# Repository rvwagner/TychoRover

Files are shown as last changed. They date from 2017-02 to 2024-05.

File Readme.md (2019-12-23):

# Tycho Rover Code

This project contains the code needed to drive the Tycho prototype lunar rover.  Currently, it is set up to drive a 1/10th-scale model using an XBox 360 controller.

There is also an [OpenSCAD][] file that can be used to 3D print a copy of the scale model.  There are detailed assembly instructions and a parts manifest at the top of that file.  Be warned that the central frame part is larger than most 3D printers- it should be possible to change the scale factor (variable `X`) to a smaller number (e.g. `25.4/11` or `25.4/12` for 1/11 or 1/12th scale, respectively) to make it fit on your printer's bed, although I have not tested that everything fits together at other scales.  You may also need to adjust the `margin` and `innermargin` variables for your printer.

## Dependencies

Requires that [ROS][] be installed (tested on ROS Kinetic Kame on Ubuntu 16.04), and requires the following ROS packages: 
- [Joy][]: `sudo apt-get install ros-kinetic-joy`
- [ROSSerial][]: `sudo apt-get install ros-kinetic-rosserial`
- [ROSSerial_Arduino][]: `sudo apt-get install ros-kinetic-rosserial-arduino`
- [ROSBridge][]: `sudo apt-get install ros-kinetic-rosbridge_suite`

Requires that the [Arduino][] IDE be installed: `sudo apt-get install arduino`

### For the CAN stuff [in progress]

- [CANard][]

    `git clone https://github.com/normaldotcom/CANard.git`
    
    `cd CANard`
    
    `[sudo] python setup.py install`

- (if using SocketCAN) [can-utils][]: `sudo apt install can-utils`
- (if using SocketCAN) slcan kernel module, if not already built [instructions](https://wiki.linklayer.com/index.php/CANtact_on_Raspberry_Pi).

The CANard module requires Python 3 (todo: figure out why), while the default ROS Python support in Kinetic is Python 2.  You may need to specially install Python 3 moduels for ROS:

    `sudo apt-get install python3-catkin-pkg-modules`

    `sudo apt-get install python3-rospkg-modules`

### Firefox

The GUI requires Firefox.  Unfortunately, Firefox 53 and later are broken on Raspberry Pi MATE Ubuntu.  To install, first uninstall Firefox, then download and install version 52:

    sudo apt-get purge firefox
    wget 'http://ports.ubuntu.com/pool/main/f/firefox/firefox_52.0.2+build1-0ubuntu0.12.04.1_armhf.deb'
    sudo dpkg -i firefox_52.0.2+build1-0ubuntu0.12.04.1_armhf.deb
    sudo apt-mark hold firefox

## Running the code

There is a launch file that starts up all the required ROS nodes:

    roslaunch tycho tycho.launch

Once the roslaunch file has finished, go to the `web/index.html` file in Firefox to view the GUI interface.

## Controls

On an XBox 360 controller, the controls are as follows:
- Left stick: Drive and steer
- A button: Enable driving in reverse (otherwise pulling stik back brakes)
- B button: Change steering mode to strafing
- X button: Emergency stop (disabled by allowing stick to return to neutral)

## Useful command-line snippets

Rebuilding ROS Arduino libraries:

    source ~/catkin_ws/devel/setup.bash      # Must re-source the workspace, even if you already have?
    rm -rf ~/sketchbook/libraries/ros_lib/   # Need to delete the libraries before rebuilding them
    rosrun rosserial_arduino make_libraries.py ~/sketchbook/libraries/

[ROS]: http://wiki.ros.org/ROS/Installation
[Joy]: http://wiki.ros.org/joy
[ROSSerial]: http://wiki.ros.org/rosserial
[ROSSerial_Arduino]: http://wiki.ros.org/rosserial_arduino
[ROSBridge]: http://wiki.ros.org/rosbridge_suite
[Arduino]: http://arduino.cc
[OpenSCAD]: http://www.openscad.org
[can-utils]: https://github.com/linux-can/can-utils
[CANard]: https://github.com/normaldotcom/CANard

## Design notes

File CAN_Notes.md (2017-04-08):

# CAN/CANable/Ubuntu Notes

CANable info page:
canable.io

Need to install can-utils:

    sudo apt install can-utils

On Raspberry Pi, also need to install slcan kernel module separately:
https://wiki.linklayer.com/index.php/CANtact_on_Raspberry_Pi

To get CANard installed,

    git clone https://github.com/normaldotcom/CANard.git
    cd CANard
    [sudo] python setup.py install
    [cd ..; rm -rf CANard/]

- - - 

To test:

    sudo modprobe can
    sudo modprobe slcan
    sudo slcand -o -c -s5 /dev/ttyACM0 can0
    sudo ifconfig can0 up

To automatically load the kernel modules on boot, add the lines "can" and "slcan" to `/etc/modules`.

Do not use slcand if you are using CANard's cantact module.

Test commands:

    candump can0 & # Or run without backgrounding in a separate window
    cansend can0 201#000A.002D

Be warned that apparently if there isn't something on the other end recieving messages, the transmit buffer fills up after ~10 messages.

# CAN and RoboTeq Controllers

CAN commands are always executed
MicroBASIC is identical priority to Serial, and are also subject to the watchdog timer.
In non-Serial modes, the controller will still respond to info queries over serial wihtout affecting control. DItto queries over CAN.

Serial section starts page 141
- They advise against using USB connection in the field- RS232 is more resilient to eletrical disruptions.
- Commands are not case-sensitive
- Underscore is an alias of carriage return
- Default watchdog is 1sec

CAN sections are 149 and ... and 169 (CANopen)
- Supports RawCAN, MiniCAN, CANopen (I know that's a ROS node for this), and RoboCAN
- - MiniCAN is a subset of OpenCAN
- - RoboCAN is proprietary, but designed for networking RoboTeq controllers
- Some controllers disable CAN while USB is connected- check datasheet
- A CAN packet/frame is 11-bit header and 0-8 byte LSB payload
- CAN packets can/should/must be interpreted by MicroBASIC scripts :-D
- In MiniCAN mode, incoming packets are automatically written to VAR9-VAR16

- RoboCAN is interesting, but not useful for us without building a custom RoboCAN-interpreting node.  Since a MiniCAN node would also need to be custom (but might be possible to build with just config files using ros_canopen), there will be no particular effort savings.

- Need to refer to general CAN documentation for bit-rate given our cable length.  Can probably hit the 1Mbps level, though default is 125kbps.

- CANopen may be a better way to go, assuming there's a general way to send data- they have a CANopen-compliant dictionary on page 173, which should allow building the ros_canopen config files.
- - As in MiniCAN, Controller will automatically transmit up to four types of packet containing settable values (VAR1-8) at an adjustable frequency (TPDO1-4).  Slight difference from MiniCAN in that only 8 vars are transmitted, as opposed to 4 4-byte, 4 2-byte and 32 bools. (Verify this in practice.)
- - As in MiniCAN, the RPDO1-4 packets write to VAR9-16. (Same difference as above.)
- - New part from CANopen is the ability to request and command specific values, bypassing the MicroBASIC script (such as e-stop)
- https://www.amazon.com/dp/B00ZW8N930/
- https://github.com/b/libusbcan
- This seems to be the go-to CAN adaptor: ~$200: http://www.peak-system.com/PCAN-USB.199.0.html?&L=1
- Here's a $25 version (out of stock) that is likely to do everything we need: http://protofusion.org/wordpress/2015/05/the-canable-a-small-usb-to-can-adapter/

- - -

MicroBASIC
- Integer (32bit) and boolean variables only - limit 1024/4096 ints and 1024 bools
- (I'll send the motor commands in RPM and radians, in order to avoid any need to update the controller code if the system layout changes?  No, it needs to know the tire diameter and steering arm length to function, so I might need to make those writable...)
- All variables set to 0/false on script first load/controller reset
- One of their suggested script actions is the limit the amp range based on heatsink temperature.
- scripts are activated every 1ms, after motion control processing is done.  Motor control takes priority.  They estimate ~50 lines of execution per activation.  Serial print is limited to 32 char/activation.
- Can upload scripts saved in .hex format from PC Utility over serial (page 183)
- NEVER set a script to auto-run unless you've made sure it doesn't crash immediately- if it does, you may need to reflash the firmware.

- - -

NUC-side CAN node:
- probably use ros_canopen for the actual communication
- Have a custom node watching the CAN node's messages
- - Track heartbeats, if any node goes silent for too long, throw an error
- - - Some level of control system should throw an estop (or harsh speed limit) if a controller goes out
- - - Probably the same level that keeps track of what the motor parameters are- call it "self-analysis"
- - When a status message (TPDO) comes in, translate to the appropriate "sensor" topics based on source ID, message type
- - If I do a single "motor status" topic, then send either when heartbeat fails or when last TPDO of the set from a controller comes in
- May have a separate node for transmission (why not?)
- - When a motor_command_final comes in, translate into CAN messages, publish to whatever ros_canopen takes
- - When an e-stop command comes in, send e-stop broadcast, as well as targeted "stop" messages.

## Manual NUC-side notes ##

CANsend documentation:
https://github.com/linux-can/can-utils/blob/master/cansend.c

Packet format:
    [three-hex-id]#[0-8 char hex data, with optional '.' separators]
    [header 0x000]#[data 0x00...]

Outgoing from controller: (not sure what Node ID is, as there isn't an obvious way to set it...  Probably broadcast.)
TPDO1: 0x180 & Node ID
TPDO2: 0x280 & Node ID
TPDO3: 0x380 & Node ID
TPDO4: 0x480 & Node ID

Incoming to controller:
RPDO1: 0x200 & Node ID
RPDO2: 0x300 & Node ID
RPDO3: 0x400 & Node ID
RPDO4: 0x500 & Node ID

So, to send RPDO1 to Node 1 with data 10,45:
201#000A.002D

E-stop Node 1 (see page 175):
Not sure what the "01" in the data is about. Seems unused.
601#8.2C.200C.00.01000000     # E-stop all channels
601#8.2C.200D.00.01000000     # Release e-stop
601#8.2C.200E.00.01000000     # "Stop [channel 1] in all modes", arg is channel

0x200E: Stop in all modes (command name MS)
- "The MS command is similar to the EX emergency stop command except that it is applied to the speci ed motor channel"

setcommand(_MSTOP, channel)

- - -

# MicroBASIC Script #

' See Page 210 for command, page 227 for queries; page 305 for config values ; page 344 for CAN bus

' Input: speed, in tenths of an RPM
'        angle, in tenths of a degree
'        scale factor = steerArmLength/tireRadius * 100
'        Heartbeat: any non-0 value that must be sent more often than HEARTBEAT_RECIEVE_RATE

#define STEER_BRAKE_PIN xx
#define DRIVE_BRAKE_PIN xx
#define COMMANDED_SPEED VAR9
#define COMMANDED_ANGLE VAR10
#define SPEED_SCALE_FACTOR_INPUT VAR11
#define NUC_IS_ALIVE VAR12
#define DATA_SEND_RATE 200
#define HEARTBEAT_RECIEVE_RATE 1000

' Use defines for readability and to allow for easy reversal of whether high or low activates the brakes
' _D0 is set pin low, _D1 is set pin high
#define BRAKES_ON _D0
#define BRAKES_OFF _D1

#define REPORT_TIMER = 1
#define KEEPALIVE_TIMER = 2

' First, make certain the brakes are on.
' They will be on when the controller is off.
SetCommand(BRAKES_ON, DRIVE_BRAKE_PIN)
SetCommand(BRAKES_ON, STEER_BRAKE_PIN)

' Set up status reporting
SetConfig(_CEN, 1)                  ' Start CANopen (comes with a default 100ms heartbeat)
SetConfig(_CTPS, 1, DATA_SEND_RATE) ' Send VAR1,2 every DATA_SEND_RATE ms
SetConfig(_CTPS, 1, DATA_SEND_RATE) ' Send VAR3,4 every DATA_SEND_RATE ms
SetConfig(_CTPS, 1, DATA_SEND_RATE) ' Send VAR5,6 every DATA_SEND_RATE ms
SetConfig(_CTPS, 1, 0)              ' Do not send VAR7,8

' Other initialization stuff
Max_Speed = GetConfig(MXRPM, 1)

' Wait for the controlling computer to check in and set the scaling parameter
GoSub SafeUntilSignal
Speed_Scale_Factor = SPEED_SCALE_FACTOR_INPUT

SetTimerCount(REPORT_TIMER, DATA_SEND_RATE)
SetTimerCount(KEEPALIVE_TIMER, HEARTBEAT_RECIEVE_RATE)

loop:
    ' (adjustments based on temperature?)
    
    Current_Steering_Speed = GetConfig(_S, 2) 'Get actual steering speed in RPM
    Current_Drive_Speed = GetConfig(_S, 1) 'Get actual steering speed in RPM
    
    ' (Current_Steering_Speed * Speed_Scale_Factor / 100) is the angular
    '  speed needed to coordinate the tire with the steering
    Final_Drive_Speed = COMMANDED_SPEED + Current_Steering_Speed * Speed_Scale_Factor / 100
    
    ' Convert angle in tenth-degrees to -1000/+1000 range
    Final_Angle = COMMANDED_ANGLE * 10 / 9

    If Final_Angle = GetValue(_F, 2) Then
        SetCommand(BRAKES_ON, STEER_BRAKE_PIN)
    Else 
        SetCommand(BRAKES_OFF, STEER_BRAKE_PIN)
        SetValue(_G, 2, Final_Angle)
    End If
    
    If Final_Drive_Speed = 0 && Current_Drive_Speed = 0 Then '[or braking commanded?]
        SetCommand(BRAKES_ON, DRIVE_BRAKE_PIN)
    Else
        SetCommand(BRAKES_OFF, DRIVE_BRAKE_PIN)
    End If
    
    If Final_Drive_Speed <> Current_Drive_Speed Then
        ' apply motor speed to drive motor
        SetValue(_G, 1, Final_Drive_Speed*100/Max_Speed)
    End If
    
    ' Copy motor status if it is time
    If GetTimerState(REPORT_TIMER) = 1 Then
        GoSub ReportParameters
        SetTimerCount(REPORT_TIMER, DATA_SEND_RATE)
    End If
    
    ' Check that the controller heartbeat has occurred
    If GetTimerState(KEEPALIVE_TIMER) = 1 Then
        If NUC_IS_ALIVE = 0 Then
            GoSub SafeUntilSignal
        End If
        NUC_IS_ALIVE = 0
        SetTimerCount(KEEPALIVE_TIMER, HEARTBEAT_RECIEVE_RATE)
    End If
    
    ' Wait until next chronon- er, cycle (is there a sync function?)
    wait(1)
GoTo loop

' Parameter-reporting subroutine
ReportParameters:
    VAR1 = 0
    VAR2 = 0
    VAR3 = 0
    VAR4 = 0
    VAR5 = 0
    VAR6 = 0
    VAR7 = 0
    VAR8 = 0
Return

' safe-until-signal subroutine
SafeUntilSignal:
    ' Clear the flag that set by the NUC's "heartbeat" RPDO
    NUC_IS_ALIVE = 0
    
    ' Stop motors
    SetValue(_G, 1, 0)
    setcommand(_MSTOP, 2)
    ' TODO: See if there's an actual "stop" command for position motors other than this psuedo-e-stop
    
    ' Wait until both are stopped before signaling brakes
    While GetConfig(_S, 2) <> 0 ' Steering speed (will probably hit 0 first)
        wait(1)
    End While
    SetCommand(BRAKES_ON, STEER_BRAKE_PIN)
    
    While GetConfig(_S, 1) <> 0 ' Driving speed
        wait(1)
    End While
    SetCommand(BRAKES_ON, DRIVE_BRAKE_PIN)
    
    ' Wait for a signal
    While NUC_IS_ALIVE = 0
        wait(1)
    End While
Return

' Dead simple CAN test
SetConfig(_CEN, 1)       ' Start CANopen
SetConfig(_CTPS, 1, 200) ' Send VAR1,2 every 200 ms

loop:
    VAR1 = VAR9 + 3
    VAR2 = VAR10 * 2
    wait(10)
GoTo loop

' Slightly more complicated CAN test
' Added defines, timer, and subroutine call

#define COMMANDED_SPEED VAR9
#define COMMANDED_ANGLE VAR10
#define DATA_SEND_RATE 200

#define REPORT_TIMER = 1

' Set up status reporting
SetConfig(_CEN, 1)                  ' Start CANopen (comes with a default 100ms heartbeat
SetConfig(_CTPS, 1, DATA_SEND_RATE) ' Send VAR1,2 every DATA_SEND_RATE ms
SetConfig(_CTPS, 1, 0) ' Do not send
SetConfig(_CTPS, 1, 0) ' Do not send
SetConfig(_CTPS, 1, 0) ' Do not send VAR7,8

SetTimerCount(REPORT_TIMER, DATA_SEND_RATE)

loop:
    ' Set report variables
    If GetTimerState(REPORT_TIMER) = 1 Then
        GoSub ReportParameters
        SetTimerCount(REPORT_TIMER, DATA_SEND_RATE)
    End If
    
    ' Wait until next cycle
    wait(1)
GoTo loop

' Parameter-reporting subroutine
ReportParameters:
    VAR1 = COMMANDED_SPEED + 3
    VAR2 = COMMANDED_ANGLE * 2
Return

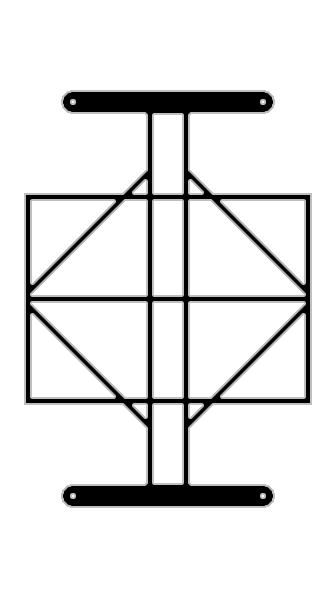
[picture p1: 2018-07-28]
web/images/tychoChassis.png

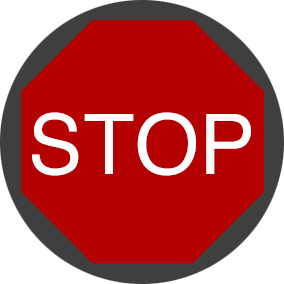
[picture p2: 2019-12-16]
web/images/OverlayStop.png

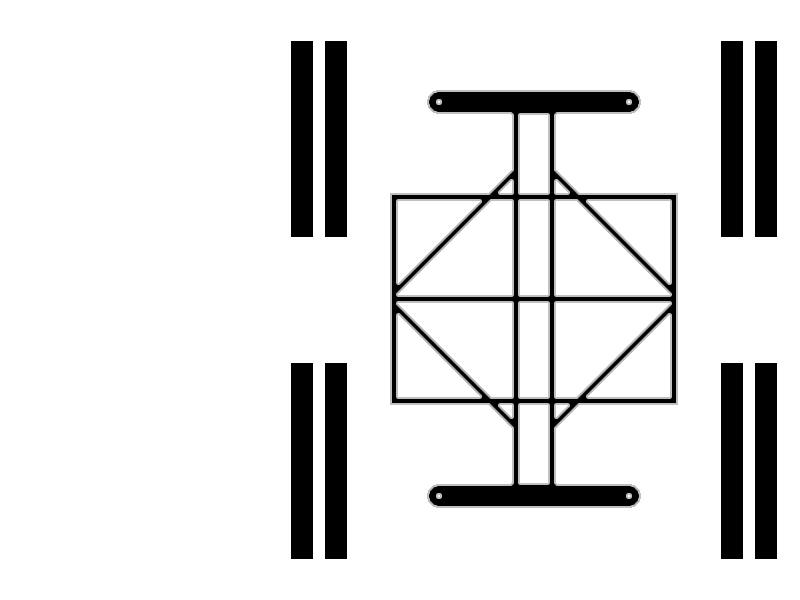
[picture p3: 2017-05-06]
web/images/TychoHUD_Background.png

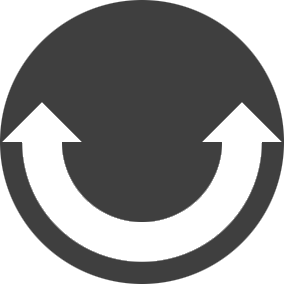
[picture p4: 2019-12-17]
web/images/OverlayOrbit.png

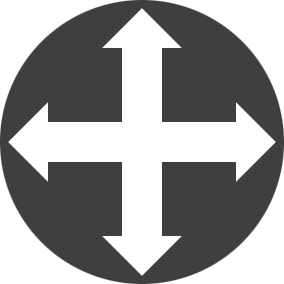
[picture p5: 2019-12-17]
web/images/OverlayStrafe.png

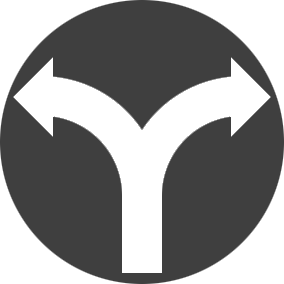
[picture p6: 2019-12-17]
web/images/OverlayNormal.png

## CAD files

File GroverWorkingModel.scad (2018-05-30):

/*
Parts manifest:
- Breadboard jumper cables (square ends).  You will need both male->male and
  male->female (and ideally a couple female->female ones to cut up to make splitters)
- DROK four-channel speed controller - https://www.amazon.com/gp/product/B017FZF42G
- Arduino Uno
- 4x TowerPro SG90 micro servos (or equivalent cheap knock-offs) - https://www.amazon.com/gp/product/B015H5AVZG
- 4x extra screws of the same size as the mounting screws that come with the servos
- 4x 12V micro gearmotors (I used 175rpm ones) - https://www.sparkfun.com/products/12205
- 8-12V battery (I used a 3S LiFePO4 9.9V battery rated at 5C draw and 1800mAh capacity) - https://www.amazon.com/gp/product/B00URCLJ6U
- Suitable connector for your battery (I converted mine to use Anderson PowerPoles)
- Light-duty wire for powering motors (I used 22AWG Sparkfun hookup wire) - https://www.sparkfun.com/products/8023
- Mini zip-ties (DIMENSIONS)
- 3D printer- 


Assembly instructions:
1) Print out all parts (see end of file).  You may wish to start by printing one of
   each part (epecially the Motor Grippers) to check the fit for your printer.
1x Frame
2x Front Beams (or 1x Front Beam and 1x Front Beam With Pi Mount)
4x Motor Grippers (check the printing path preview to make sure that there is only a single layer between the servo horn cavity on the bottom and the screw-hole above it)
4x Wheels
4x Wheel Grippers
Assorted mounting hardware and wire management clips as desired

2) Slot Front Beams onto Frame (may need either mallet or glue, depending on fit).
   Wire management loops should be on on the bottom, servo mounts on the top (the
   side of the main frame with the large flat plate is the bottom).

3) Screw micro servos onto Front Beams.  Run the servo wires through the opening
   where the Frame meets the Front Bar from bottom to top.

4) Carefully(!) slide motors into the Motor Grippers.  If a side clip snaps off,
   you may want to re-print the gripper (they are a bit fragile).  Whether you
   reprint after failures or not, anchor the motor in place using a small zip-tie
   wrapped around the clips in the slot provided.

5) Insert a small single-armed servo horn into the circular opening on the
   bottom of each Motor Gripper.  It should slide all the way in and snap into
   a position entirely recessed into the part.

6) Push a horn+Gripper onto each servo, and make sure that when the Gripper is
   in-line with the Front Beam, the servo is near the center of its range.  The
   Gripper should be able to turn 90 degrees in each direction.  Screw the
   Gripper to the servo using a longer screw than the small bolts provided- the
   mounting screws worked nicely on my servos, although I then needed to get
   extra screws to mount the servos to the frame.

7) For each motor, strip one end of a pair of ~16" wires, and run the stripped
   end through the wire management loop on the Front Bar closest to the motor,
   and then through the loop on the gripper.  Solder the wires to the motor.
   You may want to use a dab of hot glue to anchor the wires in place at the
   Gripper wire management loop to eliminate all strain on the motor conections.
   Run the other end of the wires up between the two bars that run the length
   of the Frame.

8) Push the mounting brackets into the mounting holes in the corners of the
   speed controller board, and clip it onto one side of the frame, with the
   motor outputs pointing towards the center fo the frame.  Do the same with
   the Arduino, with the digital outputs towards the center of the frame.

9) Trim motor power wires to length, strip the ends, and insert them into
   appropriate channels on the motor controller.  I used the following assignments:
Out1/2: Back Left
Out3/4: Back Right (reverse the + and - wires relative to the left motors)
Out5/6: Front Left
Out7/8: Front Right (reverse the + and - wires relative to the left motors)

10: Solder up four splitter jumper wires, with one male end and two female
    ends.  These will control the forward/backward pins on the speed
    controller (using two arduino pins for the left motors and two for the
    right).  I used the following pin connections:
Arduino    DROK
   2   -> IN1/IN5
   4   -> IN2/IN6
   7   -> IN3/IN7
   8   -> IN4/IN8

11: Using normal male->female jumper cables, connect Arduino PWM pins to
    the DROK enable pins, and power the Arduino from the DROK's 5V regulator:
Arduino    DROK
   3   -> ENA (channels 1-2)
   5   -> ENB (channels 3-4)
   6   -> ENA (channels 5-6)
  11   -> ENB (channels 7-8) (note that the Servo library disables PWM on pins 9 and 10)
 VIN   -> +5 (I used the one next to IN1)
 GND   -> GND

12) Connect a connector for your battery to the VCC and GND screw terminals
    on the inboard side of the DROK board.  At this point you can plug in
    your battery, upload code to the arduino, and verify that the motors are
    wired up correctly.

13) Create a power bus for the servos.  I soldered a ~5" wire across four
    male header pins (once for ground, once for power), glued the two sets
    of header pins together, and wrapped heatshrink around them (with slots
    cut to allow the long ends of the header pins to get out).  A less-
    finicky insulation method will probably be better, as long as it's
    secure, and leaves room to plug jumper wires into the signal wires of
    the servo plugs.  Connect this power bus to the +5 and GND screw
    terminals on the outer edge of the speed controller.

14) Plug the servo cables into the power bus (red and brown on the servo
    wire go to +5V and Gnd, respectively), and run jumpers from the Arduino
    to the servo signal wires (orange):
Arduino     Servo
   9   -> Back Left
  10   -> Back Right 
  12   -> Front Left
  13   -> Front Right

15) Press a Wheel Grip onto the outside of each wheel (they should latch
    on fairly tightly), and press the wheel assembly onto the motor drive
    shaft.  The wheels should fit snugly and not feel likely to fall off.
    If they are too loose, adjust the parameters on the Wheel Grips and
    reprint them.  (Note: If a motor fails, you can flip the Wheel Grip
    around (detaching it from the wheel) to allow the wheel to spin freely
    on the drive shaft.)
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

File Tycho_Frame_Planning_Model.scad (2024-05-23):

// This file is useful for visualizing the rover pose relative to turning centers
// It also contains code for visualizing alternate rover geometries,
// based on the desired maximum wheel turning angles.
// You can print the parts, too, for a fun little desk toy.  Pit the parts together with cut-up bits of paperclip.

X = 25.4/20; // scaling factor for the frame (original is inches)

// Vehicle geometry constraints
max_vehicle_width = 71*X; // 76*X;
maxOutwardAngle   = 90 ; // e.g. max amount the front-left wheel can turn from forward to left
maxInwardAngle    =  0; // e.g. max amount the front-left wheel can turn from forward to right (minus 90 degrees)

// The LRV had a minimum turning radius of ~72.75" (1.85m), with a wheel angle of 50deg
// With our longer hinge-to-wheel distance and associated frame changes, we get that radius with a max wheel angle of 45deg

// Direction to point the wheels (see also "steeringMode" below)
wheelAngle   = 0;
turnCenterX  = 0; turnCenterY  = 72.75*X; // LRV Min Radius
//turnCenterX  = 120; turnCenterY  = 0; // Circle-strafe
//turnCenterX  = 90; turnCenterY  = 72.75*X; // Arbitrary
//turnCenterX  = 5; turnCenterY  = -20; // Perfect panorama
//turnCenterX  = 65; turnCenterY  = 0; // Perfect rovercam panorama

steeringMode = 0; // 0: wheels turn about the point defined above;   1: Wheels turn in strafing mode, at the angle defined above
//wheelAngle=$t*120-60; // Animation
//turnCenterX = -10; turnCenterY = 20; // For panoramas by the copilot
//turnCenterX = 0; turnCenterY = $t*300-150 ; // animation

//steeringMode = 1;  wheelAngle   = 45;

backboneFrame = true; // If true, make frame using full-length backbone-style bars

// Display options
showWheelSweep              = false; // Show a transparent shape over the area that the wheel can occupy
showTurnPointExclusionZones = false; // Draw thick red lines in regions where the center of rotation cannot be  for normal and strafing turns
showFullExclusionZones      = true; // Draw wedges showing the full 2D exclusion zones
showWheelDirectionLine      = true; // Draw light purple lines perpendicular to each wheel
showCurrentTurnCenter       = true; // Places a magenta cylinder at the center of rotation
useSimpleWheel              = true; // Using non-simple wheels takes much longer to render
animateTurnPoint            = true; // Center the turning point in the grid and rotate the model about that point (requires checking "Animate" in the View menu)


//dimensionDisplayUnits="meters"; dimensionDisplayMultiplier=0.0254;
dimensionDisplayUnits="inches"; dimensionDisplayMultiplier=1;

// Color definitions
// https://en.wikibooks.org/wiki/OpenSCAD_User_Manual/Transformations#color
exclusionColor      = "Red";
wheelDirectionColor = "Thistle";
turnCenterColor     = "Magenta";



//////////////////////////
// PRINTING ADJUSTMENTS //
//////////////////////////

// Radius of pins used for articulation (in this case, ordinary paperclips)
pinRadius = 1/2;
// The above scaled appropriately for BFB 3DTouch, with hole oriented horizontally/vertically
pinRadius_h = 2.0/2; 
pinRadius_v = 2.6/2; 

c_thickness = 1; // Thickness of the plates holding the wheel arms to the main body
printingBuffer = 1.4; // Extra clearance needed for the wheel arm "C"s to clear the wheel supports on the work printer


///////////////////////////////////////
//       Dimensional Variables       //
//           DO NOT TOUCH!           //
///////////////////////////////////////

$fn=200;

Y = X; // Scaling factor for the bars of the frame
bar_width = 2*Y;
bar_height = 3*Y;
end_support_bar_width = 2*Y;

tire_width = 9.6*X;
tire_radius = (32/2)*X;
tire_buffer = (5/2.54)*X; // Minimum clearance between tire and frame

wheelSupportWidth = 6*X;//bar_width * 2;
wheelSupportHeight = 6*Y;
chassis_to_hinge = tire_radius + tire_buffer;
wheelSupportLength = chassis_to_hinge + wheelSupportWidth/2;
hinge_to_wheel = wheelSupportWidth/2 + tire_buffer;

// Verical offset of wheels
wheel_mount_offset=1*X+bar_height/2;

// Measurements are to center of bars
center_length = 53*X - bar_width;
center_width = 55.45*X - bar_width;
front_length = 29*X - bar_width/2; // LRV = 29"
back_length = 29*X - bar_width/2; // LRV = 27.5"
wheelHingeYDist = max_vehicle_width/2 - tire_width - hinge_to_wheel; // Distance from centerline to wheel arm mount point
end_width = wheelHingeYDist*2 - chassis_to_hinge*2 - bar_width; // For LRV-style frame

// Distance from rover center to the front/back wheel mounts
// At closest approach between tire and center chassis section, maintain tire_buffer distance
// LRV was 45.5"
wheelHingeXDist = (center_length+bar_width)/2 + tire_buffer + sqrt( (hinge_to_wheel+tire_width)*(hinge_to_wheel+tire_width) + tire_radius*tire_radius);

// Placeholder printable wheel
tire_curve = 1*X; // Radius of the curve on the sides of the placeholder wheel
spoke_size = 1*X; // Width/thickness of the spokes in the placeholder wheel
hub_rad = 2.35*X;    // Size of the opening in the center of the placeholder wheel hub
wall_thickness = 0.5*X; // Thickness of the driving surface of the placeholder wheel

// Placeholder for steering motor
// http://www.robotmarketplace.com/products/NPC-B81HT.html
motor_length=15*X-wheelSupportWidth; // The -wheelSupportWidth is to allow clearance for the functional hinge
motor_radius=3.75/2*X;




///////////////////////////////////////
//              Modules              //
///////////////////////////////////////

////////////
// WHEELS //
////////////

module wheel_printable(){    
    module torus(r1, r2){
        rotate_extrude(convexity = 1)
            translate([r1-r2, 0, 0])
                circle(r = r2, $fn=20);
    }

    module wallBase(radius, widthmod=0){
        union(){
            translate([0,0,tire_width/2-tire_curve]) torus(radius, tire_curve);
            cylinder(tire_width - tire_curve*2 + widthmod, radius, radius, center=true);
            cylinder(tire_width + widthmod, radius-tire_curve, radius-tire_curve, center=true);
            translate([0,0,-tire_width/2+tire_curve]) torus(radius, tire_curve);
        }
    }

    module wall(){
        difference(){
            wallBase(tire_radius);
            wallBase(tire_radius-wall_thickness, 1);
        }
    }
    
    // Full wheel assembly
    wall();
    intersection(){ // Spokes and hub
        translate([0,0,(-tire_width+spoke_size)/2])difference(){
            union(){
                for(i=[0:45:179]) rotate([0,0,i]) cube([spoke_size,tire_radius*2,spoke_size], center=true);
                cylinder(spoke_size, hub_rad+spoke_size, hub_rad+spoke_size, center=true);
            }
            cylinder(spoke_size+1, hub_rad, hub_rad, center=true);
        }
        wallBase(tire_radius);
    }
}


module wheel_simple(){
    cylinder(tire_width, tire_radius, tire_radius, center=true);
}

module wheel(){
    if (showWheelDirectionLine) color(wheelDirectionColor) translate([0,0,-wheel_mount_offset])rotate([0,0,0])cylinder(1000,1,1,center=true);
    if(useSimpleWheel)
        wheel_simple();
    else
       wheel_printable();
}

module wheel_sweep(){
    t = [0,0,hinge_to_wheel+tire_width/2];
    translate(t) for(i = [-(90+maxInwardAngle):10:maxOutwardAngle]) rotate([0,180-i,0])
        translate(t) cylinder(tire_width, tire_radius, tire_radius, center=true);
}


module lrv_wheel(){
    translate([0,wheel_dist+tire_width/2,0])rotate([90,0,0])difference(){union(){
        rotate_extrude() translate([tire_radius-tire_width/2, 0, 0]) circle(tire_width/2); 
        cylinder(tire_width*0.75,tire_radius-tire_width/2,tire_radius-tire_width/2, center=true);
        
        translate([0,bar_width+0.1,tire_width/2-bar_width])cube([tire_width,bar_width,bar_width*2], center=true);
        translate([0,-bar_width-0.1,tire_width/2-bar_width])cube([tire_width,bar_width,bar_width*2], center=true);
    }
        translate([0,0,tire_width/2-bar_width])cube([tire_width,bar_width,bar_width], center=true);
    }
}


//////////////////////
// WHEEL SWING ARMS //
//////////////////////
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

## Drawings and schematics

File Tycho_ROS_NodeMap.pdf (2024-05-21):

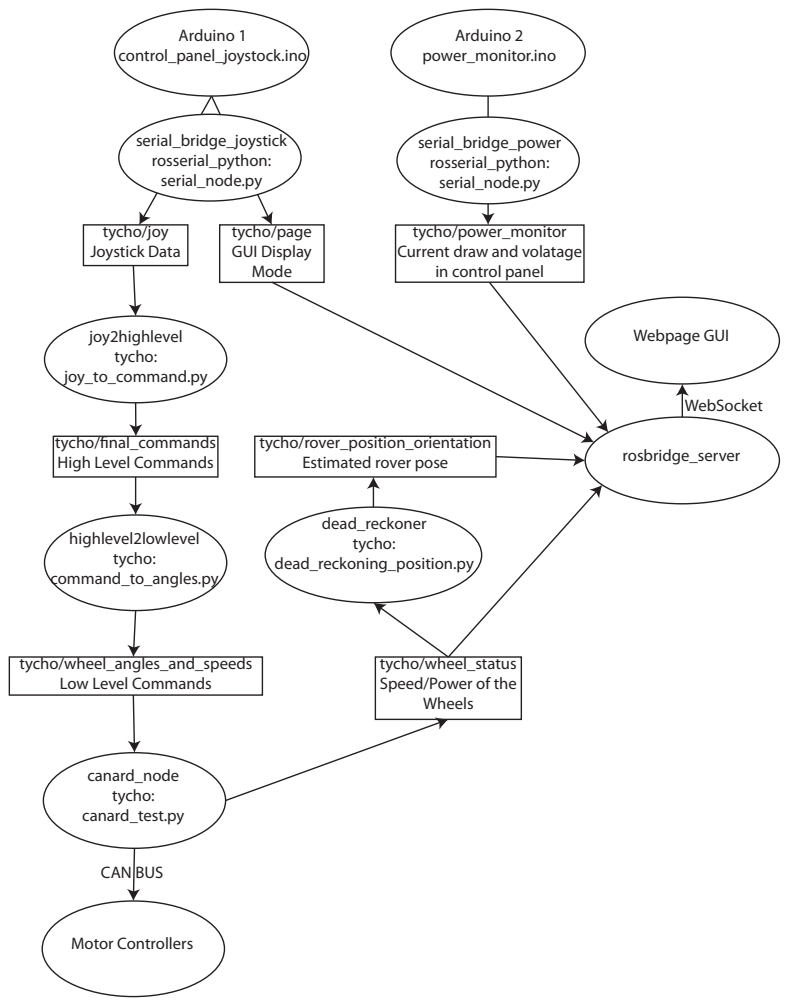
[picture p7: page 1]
tycho/joy Joystick Data; tycho/page GUI Display Mode; highlevel2lowlevel tycho: command_to_angles.py; joy2highlevel tycho: joy_to_command.py; Arduino 1 control_panel_joystock.ino; serial_bridge_joystick rosserial_python: serial_node.py; canard_node tycho: canard_test.py; Arduino 2 power_monitor.ino; serial_bridge_power rosserial_python: serial_node.py; rosbridge_server; dead_reckoner tycho: dead_reckoning_position.py; Webpage GUI; Motor Controllers; CAN BUS; WebSocket

tycho/power_monitor
Current draw and volatage
in control panel

tycho/nal_commands
High Level Commands

tycho/rover_position_orientation
Estimated rover pose

tycho/wheel_angles_and_speeds
Low Level Commands

tycho/wheel_status
Speed/Power of the
Wheels

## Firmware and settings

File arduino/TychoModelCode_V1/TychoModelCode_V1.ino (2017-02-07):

/* 


Function usage:
For direct dumb control over the motors, use the following functions for driving and steering:
setAllMotorSpeeds(int spd1, int spd2, int spd3, int spd4, int turnInPlace)
setSteeringAngles(int a1, int a2, int a3, int a4)
These simply set the motor speeds and steering angles as you command, without trying to ensure
that the rover state remains internally consistent or physically possible.  The associated ROS
topics are "motorValues" and "motorAngles", both of which are 4-value Int16MultiArrays.


For higher-level control, command a speed with 
setVehicleSpeed(int spd)
and define steering angles with either of the following, depending on whether you want to turn
or strafe/drive straight:
setAnglesFromTurnCenter(float turnCenterX, float turnCenterY)
float setAnglesStrafing(float angle)
These functions act to ensure that the wheels on the rover are at appropriate and useful angles,
and that the wheel speeds are scaled to minimize slippage.  The associated ROS topics are 
"vehicleDirection": Int16MultiArray, three values: strafingAngle (degrees; ignored if <-90),
                    turnCenterX, turnCenterY (both in cm; ignored if strafingAngle >= -90)
"vehicleSpeed": Int16, range -100 to +100.  If spinning in place, positive is spinning CCW.

*/
#define ROS

#ifdef ROS
#include <ros.h>
#include <tycho/WheelAnglesSpeeds.h>
ros::NodeHandle  nh;
#endif

#include <Servo.h>

const int leftMotorsForwardPin   = 2; // Motors 1+3 (right side), 2+4 (left side) will always
const int leftMotorsBackwardPin  = 4; // spin in the same direction, although not at the same
const int rightMotorsForwardPin  = 7; // speed, saving four pins
const int rightMotorsBackwardPin = 8;

const int frontRightMotorSpeedPin = 3;  // Motor 1
const int frontLeftMotorSpeedPin  = 5;  // Motor 2
const int backRightMotorSpeedPin  = 6;  // Motor 3
const int backLeftMotorSpeedPin   = 11; // Motor 4 // Servo library disables PWM on pins 9 and 10

const int frontRightServoPin = 9; // Those saved pins are used for steering servos
const int frontLeftServoPin  = 10;
const int backRightServoPin  = 12;
const int backLeftServoPin   = 13;

const int deadband = 0; // Ignore speed commands between -deadband and +deadband

Servo s1;
Servo s2;
Servo s3;
Servo s4;
Servo servos[4];
int servo_offsets[4] = {-8, -5, -5, 6}; // Add to 90 to get the actual zero-point

float jointX[4] = {11.7, 11.7, -11.7, -11.7}; // +X is forward, numbers in cm
float jointY[4] = {-6.35, 6.35, -6.35, 6.35}; // +Y is left
float steeringArmLength = 3.65; // Approximate distance from turning point to the 

float speedMultipliers[4] = {1.0, 1.0, 1.0, 1.0};

int currentSpeed = 0; // Stores the last commanded speed value

int posX = 0;
int posY = 0;
int spd  = 0;
int straight = 1;


struct Motor {
  int fwdPin; // Any digital out -> IN1/IN3
  int bckPin; // Any digital out -> IN2/IN4
  int spdPin; // Any PWM -> ENA/ENB
  char curSpd; // Range -100 to +100
} m1, m2, m3, m4;

void initMotor(struct Motor *m, int s, int f, int b){
  m->fwdPin = f;
  m->bckPin = b;
  pinMode(m->fwdPin, OUTPUT);
  pinMode(m->bckPin, OUTPUT);
  if(s>=-1){
    m->spdPin = s;
    pinMode(m->spdPin, OUTPUT);
  }
  m->curSpd = 0;
}


/////////////
// DRIVING //
/////////////

// Set motor speed on a scale of -100 to +100
void setMotorSpeed(int spd, struct Motor m){
  m.curSpd = spd;
  if(m.fwdPin >= 0 && m.bckPin >= 0){
    if(spd > deadband){
      digitalWrite(m.fwdPin, HIGH);
      digitalWrite(m.bckPin, LOW); 
    } else if (spd < deadband) {
      digitalWrite(m.fwdPin, LOW);
      digitalWrite(m.bckPin, HIGH);
    } else { // Center deadband
      digitalWrite(m.fwdPin, LOW);
      digitalWrite(m.bckPin, LOW);
    }
  }
  //Serial.print( (50+abs(spd)*2), DEC); Serial.print(" "); Serial.println(spd, DEC);
  
  // Optionally set a PWM signal for the motor speed
  // Limits output to 255, just in case the input spd is >100
  if(m.spdPin >= 0) analogWrite(m.spdPin, min((50+abs(spd)*2), 255) );
}

// Directly set the speeds of all motors
// Speed arguments can be in the range -100 to +100
// If turnInPlace is true, the left-hand wheel directions will be automatically reversed.
void setAllMotorSpeeds(int spd1, int spd2, int spd3, int spd4, int turnInPlace){
  int leftMultiplier=1;
  if(turnInPlace) leftMultiplier = -1; // Reverse the left-hand motors to turn in place
  
  // Approximation of the current center-of-vehicle speed, needed for higher-level command system
  // Ideally these systems won't be used together, but just in case...
  // TODO: Calculate actual center-of-vehicle speed based on wheel angles?
  currentSpeed = (spd1+spd2+spd3+spd4)/4;
  
  setMotorSpeed(spd1               , m1);
  setMotorSpeed(spd2*leftMultiplier, m2);
  setMotorSpeed(spd3               , m3);
  setMotorSpeed(spd4*leftMultiplier, m4);
}

// Set the motor speeds such that the center of the vehicle travels at the commanded speed.
// Valid speed values range from -100 to +100
// Or, if the vehicle is turning about a point within the frame, sets the speed of
// the outer-most wheel to the commanded speed (and other speeds are scaled accordingly).
void setVehicleSpeed(int spd){
  currentSpeed = spd;
  // Set individual wheel speeds based on multiplier array
  // That array inherently takes care of the direction-reversal for spin-in-place
  int modifiedSpeeds[4] = {(int)(spd*speedMultipliers[0]),
                           (int)(spd*speedMultipliers[1]),
                           (int)(spd*speedMultipliers[2]),
                           (int)(spd*speedMultipliers[3])};
  
  // If any wheel is above max speed, scale all speeds down
  int maxSpd = 0;
  for (int i = 0; i < 4; i++) if(abs(modifiedSpeeds[i]) > maxSpd) maxSpd = abs(modifiedSpeeds[i]);
  if (maxSpd > 100) {
    float scaleFactor = 100.0 / maxSpd;
    Serial.println(scaleFactor, DEC);
    for (int i = 0; i < 4; i++) modifiedSpeeds[i] *= scaleFactor;
  }

  /* Serial.print("Speed ");
  Serial.print(modifiedSpeeds[0], DEC);  Serial.print(" ");
  Serial.print(modifiedSpeeds[1], DEC);  Serial.print(" ");
  Serial.print(modifiedSpeeds[2], DEC);  Serial.print(" ");
  Serial.print(modifiedSpeeds[3], DEC);  Serial.println(); */
  
  // Command speed controller
  setMotorSpeed(modifiedSpeeds[0], m1);
  setMotorSpeed(modifiedSpeeds[1], m2);
  setMotorSpeed(modifiedSpeeds[2], m3);
  setMotorSpeed(modifiedSpeeds[3], m4);
}



//////////////
// STEERING //
//////////////



// Commands the servos to go to specified angles
// Returns the estimated time until they reach that angle in ms
int setSteeringAngles(int a1, int a2, int a3, int a4){
  // Get amouont of maximum change in angle for calculating update duration
  int maxAngleChange = abs(a1 - servos[0].read());
  int change = abs(a2 - servos[1].read());
  if (change > maxAngleChange) maxAngleChange = change;
  change = abs(a3 - servos[2].read());
  if (change > maxAngleChange) maxAngleChange = change;
  change = abs(a4 - servos[3].read());
  if (change > maxAngleChange) maxAngleChange = change;
  
  servos[0].write(a1+servo_offsets[0]);
  servos[1].write(a2+servo_offsets[1]);
  servos[2].write(a3+servo_offsets[2]);
  servos[3].write(a4+servo_offsets[3]);

  return maxAngleChange*2; // Servo nominally rotates at 500deg/sec
}

// Commands the steering servos to go to appropriate angles for the vehicle to turn
// about the specified position in x/y space (+X is forward, +Y is left, units in cm)
// Also adjusts the current motor speeds to be correct for the differing ditances from
// the turning center (WARNING: Does not play nicely with setAllMotorSpeeds; use 
// setVehicleSpeed instead).
// Returns estimated time until the wheels reach the target angles in ms.
int setAnglesFromTurnCenter(float turnCenterX, float turnCenterY){
  int angles[4] = {0,0,0,0};
  float turnPointDistance = sqrt(turnCenterX*turnCenterX + turnCenterY*turnCenterY);
  float maxMultiplier = 0.0;
  for (int i = 0; i < 4; i++){
    float distY = turnCenterY-jointY[i];
    float distX = turnCenterX-jointX[i];
    angles[i] = atan(distX/distY)*180/3.14+90;
    
    // Calculate the distance to the turning point based on whether steering arm points 
    // towards or away from the turn point
    float distTotal = sqrt(distX*distX + distY*distY);
    if (turnCenterY/jointY[i] > 1){ // Same sign and abs(turnCenterY) > abs(self.jointY)
      distTotal -= steeringArmLength;
    } else { // Arm points away from point
      distTotal += steeringArmLength;
    }

    // For very small offsets from turn-in-place, make all wheel speeds match here to avoid rounding issues
    if (turnPointDistance <= 0.01)  speedMultipliers[i] = 1.0;
    else speedMultipliers[i] = distTotal/turnPointDistance;
    if (speedMultipliers[i] > maxMultiplier) maxMultiplier = speedMultipliers[i];
  }
  
  // If turn point is interior to wheels, adjust multipliers to:
  // A) Max out at 1.0
  // B) Reverse the left-hand wheels (2 and 4; indices 1 and 3)
  // TODO: Add variables for joint X and Y positioins in general, rather than relying on joint[1] being positive
//  Serial.print(abs(turnCenterX), DEC); Serial.print(" ");
//  Serial.print(jointX[1], DEC); Serial.print(" ");
//  Serial.print(abs(turnCenterY), DEC); Serial.print(" ");
//  Serial.print(jointY[1], DEC); Serial.println();
  if ( abs(turnCenterX) < jointX[1] && abs(turnCenterY) < jointY[1] ) {
    speedMultipliers[0] =  speedMultipliers[0] / maxMultiplier;
    speedMultipliers[1] = -speedMultipliers[1] / maxMultiplier;
    speedMultipliers[2] =  speedMultipliers[2] / maxMultiplier;
    speedMultipliers[3] = -speedMultipliers[3] / maxMultiplier;
  }

  
  
  //Serial.print("Mults ");
  //Serial.print(speedMultipliers[0], DEC);  Serial.print(" ");
  //Serial.print(speedMultipliers[1], DEC);  Serial.print(" ");
  //Serial.print(speedMultipliers[2], DEC);  Serial.print(" ");
  //Serial.print(speedMultipliers[3], DEC);  Serial.println();
  
  //Serial.print("Angle ");
  //Serial.print(angles[0], DEC);  Serial.print(" ");
  //Serial.print(angles[1], DEC);  Serial.print(" ");
  //Serial.print(angles[2], DEC);  Serial.print(" ");
  //Serial.print(angles[3], DEC);  Serial.println(); 

  // Adjust the current drive speed based on the new speed multipliers
  setVehicleSpeed(currentSpeed);

  // Actually command the servos
  return setSteeringAngles(angles[0], angles[1], angles[2], angles[3]);
}

// Set the steering angle to put all wheels parallel at the specified angle
// Valid angles go from -90 to +90, with 0 being straight ahead and +90 being to the left
// Returns estimated time until the wheels reach the target angles in ms.
float setAnglesStrafing(float angle){
  // No speed multiplication needed in this drive mode
  speedMultipliers[0] = 1.0;
  speedMultipliers[1] = 1.0;
  speedMultipliers[2] = 1.0;
  speedMultipliers[3] = 1.0;
  
  // Adjust the current drive speed based on the new speed multipliers
  setVehicleSpeed(currentSpeed);
  
  return setSteeringAngles(angle+90, angle+90, angle+90, angle+90);
}


/////////////////////////
// Autopilot Demo Loop //
/////////////////////////

void demoLoop(){
  
  // Demo loop
  setVehicleSpeed(0); delay(200);

  // Drive forward
  delay(setAnglesStrafing(0)); // Servos take ~1/4s to rotate into position
  setVehicleSpeed(50);
  delay(1000);
  
  // pause
  setVehicleSpeed(0); delay(200);

  // Spin in place 1/4 turn
  delay(setAnglesFromTurnCenter(0,0));
  setVehicleSpeed(-50);
  delay(500);

  // Pause
  setVehicleSpeed(0); delay(200);

  // Drive in a half-circle
  delay(setAnglesFromTurnCenter(0, -23));
  setVehicleSpeed(50);
  delay(3000);

  // Pause
  setVehicleSpeed(0); delay(200);

  // TUrn back 3/4 turn
  delay(setAnglesFromTurnCenter(0,0));
  setVehicleSpeed(50);
  delay(1500);
}


///////////////////
// ROS callbacks //
///////////////////

#ifdef ROS
void rosSetMotorSpeedAngles(const tycho::WheelAnglesSpeeds& values) {
  setMotorSpeed(values.front_right_speed*100, m1);
  setMotorSpeed(values.front_left_speed*100, m2);
  setMotorSpeed(values.back_right_speed*100, m3);
  setMotorSpeed(values.back_left_speed*100, m4);
//}
//void rosSetMotorAngles(const tycho::WheelAnglesSpeeds& values) {
  setSteeringAngles(values.front_right_angle+90, 
                    values.front_left_angle+90, 
                    values.back_right_angle+90, 
                    values.back_left_angle+90);
}

// Values are strafingAngle (ignored if <-90), turnCenterX, TurnCenterY (both ignored if strafingAngle >= -90)
//void rosSetVehicleDirection(const tycho::WheelAnglesSpeeds& values) {
//  if(values.data[0] >= -90) {
//    setAnglesStrafing(values.data[0]);
//  } else {
//    setAnglesFromTurnCenter(values.data[1], values.data[2]);
//  }
//  // TODO: Publish actual angles and speeds
//}
//void rosSetVehicleSpeed(const std_msgs::Int16& value) {
//  setVehicleSpeed(value.data);
//}

ros::Subscriber<tycho::WheelAnglesSpeeds> motorSub("tycho/low_level_motor_values",&rosSetMotorSpeedAngles);
//ros::Subscriber<std_msgs::Int16MultiArray> angleSub("motorAngles",&rosSetMotorAngles);
//ros::Subscriber<std_msgs::Int16MultiArray> directionSub("vehicleDirection",&rosSetVehicleDirection);
//ros::Subscriber<std_msgs::Int16MultiArray> speedSub("vehicleSpeed",&rosSetVehicleSpeed);
#endif







////////////////
// Setup/Loop //
////////////////

void setup() {
  initMotor(&m1, frontRightMotorSpeedPin, rightMotorsForwardPin, rightMotorsBackwardPin); // SpeedPin, ForwardPin, BackPin
  initMotor(&m2, frontLeftMotorSpeedPin,  leftMotorsForwardPin,  leftMotorsBackwardPin);
  initMotor(&m3, backRightMotorSpeedPin,  rightMotorsForwardPin, rightMotorsBackwardPin);
  initMotor(&m4, backLeftMotorSpeedPin,   leftMotorsForwardPin,  leftMotorsBackwardPin);
  servos[0].attach(frontRightServoPin);
  servos[1].attach(frontLeftServoPin);
  servos[2].attach(backRightServoPin);
  servos[3].attach(backLeftServoPin);
  setSteeringAngles(90, 90, 90, 90);
  
#ifndef ROS
  Serial.begin(57600);
#else
  nh.initNode();
  nh.subscribe(motorSub);
//  nh.subscribe(angleSub);
//  nh.subscribe(directionSub);
//  nh.subscribe(speedSub);
#endif
}

void loop() {
  
//  demoLoop();
//  return;
  
#ifndef ROS
  // If not doing ROS version, check for commands on the serial port
  // WASD moves steering point, Q/E set forward-backward, Space stops.
  while (Serial.available() > 0){
    char c = Serial.read();
    switch(c) {
      case 'w': posX++; break;
      case 'a': posY+=3; break;
      case 's': posX--; break;
      case 'd': posY-=3; break;
      case 'c': straight = !straight; break;
      case 'q': spd++; break;
      case 'e': spd--; break;
      case ' ': spd=   0; break;
    }
    Serial.print(spd, DEC);
    Serial.print(" ");
    Serial.print(posX, DEC);
    Serial.print(" ");
    Serial.println(posY, DEC);

    if (straight) setAnglesStrafing(-posY);
    else setAnglesFromTurnCenter(posX,posY);
    
    setVehicleSpeed(spd);
  }
#else
  // If doing ROS version, just wait for more inputs on the command topics
  nh.spinOnce();
  delay(10);
#endif
}

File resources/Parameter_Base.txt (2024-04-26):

/tycho/speeds/
# Max speeds in mm/s; accelerations are in mm/s^2
max_wheel:    4500.0 # Maximum speed of a single wheel
max_normal:   1000.0 # Max speed for normal driving mode # TYCHO_MAX_SPEED
max_fwd:      2000.0 # Front-wheel-drive mode speed limit
max_strafe:   1000.0 # Max speed in normal strafing mode
max_spin:     1000.0 # Max speed in spin-in-place mode
max_c_strafe: 1000.0 # Max speed for circle-strafing
max_accel:    2000.0 # Max acceleration in all modes, primarily used for gentle braking
c_strafe_adjust_rate: 0.75 # m/s

/tycho/dimensions/
# All distances in meters
wheel_x_distance = 1.17
wheel_y_distance = ???
# self.jointX = rospy.get_param("/tycho/joint_x_positions")
# self.jointX = rospy.get_param("/tycho/joint_y_positions")
# self.jointX = rospy.get_param("/tycho/steering_arm_lengths")
minimum_side_radius: 1.0 
minimum_front_radius: 1.5
default_front_radius: 2.5

/tycho/status/
active_ends: FRONT_ONLY # String, "BOTH", "FRONT_ONLY", or "BACK_ONLY"

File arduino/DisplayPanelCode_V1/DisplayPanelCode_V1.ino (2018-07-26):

/*
  Circuit:            7 Segment Display 
  5v   -------------------- VCC
  GND  -------------------- GND
  32   -------------------- SS (speed display)
  34   -------------------- SS (pitch display)
  35   -------------------- SS (roll display)
  36   -------------------- SS (heading display)
  37   -------------------- SS (temperature display)
  52   -------------------- SCK
  51   -------------------- SDI
  
  Circuit:             LED Matrix Display
  30   -------------------- DIN 
  33   -------------------- CLK
  31   -------------------- CS
    
*/

#include <SPI.h>
#include <Servo.h>
#include <Wire.h>
#include <SparkFunLSM9DS1.h>
#include "LedControl.h"

#define ROS

#define LSM9DS1_M    0x1E
#define LSM9DS1_AG   0x6B

#define PRINT_CALCULATED
#define DECLINATION -10.13 //Tempe Arizona Declination
#define PRINT_SPEED 2000

#ifdef ROS
#include <ros.h>
#include <tycho/DisplayPanel.h>
ros::NodeHandle nh;
#endif



// Accelerometer object
LSM9DS1 imu;

//Pins: DIN,CLK,CS, # of displays connected
LedControl lc = LedControl(30,33,31,1);

// Warning servo motor declerations.
const int temp_warning = 3; //Motor 1
const int slope_warning = 5; //Motor 2
const int speed_warning = 7; //Motor 3
const int batt_warning = 9; // Motor 4
const int brakes_engaged = 11; // Motor 5

// 7 Segment display declerations.
const int speedPin = 32;
const int pitchPin = 34;
const int rollPin = 35;
const int headingPin = 36;
const int tempPin = 37;

float wheelSpeed = 0;
float front_left_angle = 0;
float front_right_angle = 0;
float back_left_angle = 0;
float back_right_angle = 0;
float total_amps = 0;
float battery_pct = 0;
float max_drive_temp = 0;
float roll = 0;
float pitch = 0;
float heading = 0;
//boolean baking = false;

int hottest_motor_id = 0;
char tempString[10]; // char array for printing data to displays

Servo servos[4];

///////////////////
// ROS callbacks //
///////////////////
#ifdef ROS
void rosSetDisplayValues(const tycho::DisplayPanel& values){
  
  displayValue(speedPin, values.speed);
  displayValue(tempPin, values.max_drive_temp);
  
    /* Handle warning flags on arduino?
  if(values.speed > xx)
  {
    servos[0].write(90);
  }else{
    servos[0].write(0); 
  }
  if(values.pitch > xx || values.roll > xx)
  {
    servos[1].write(90);  
  }else{
    servos[1].write(0); 
  }
  if(values.
  
  if(values.max_drive_temp > xx)
  {
    servos[2].write(90);
  }else{
    servos[2].write(0); 
  }
  
  if(values.batt_temp < xx)
  {
    servos[3].write(90); 
  }else{
    servos[3].write(0);
  }
  
  if(values.brakes_engaged = 
  */
  
  display_angles(values.front_left_angle, values.front_right_angle, values.back_left_angle, values.back_right_angle);
  
}

ros::Subscriber<tycho::DisplayPanel> displaySub("tycho/display_values", &rosSetDisplayValues);

#endif

//////////////////////////
// Display 7 Seg Values //
//////////////////////////
void displayValue(int pinNumber, float dispValue)
{
    clearDisplaySPI(pinNumber);
    
    int floatInInt;
    
    setDecimalsSPI();
    
    floatInInt = (int)(dispValue * 10); 

    sprintf(tempString, "%4d", floatInInt);
    segStringSPI(pinNumber, tempString);
    
    setDecimalsSPI();
  
}

//////////////////////////////
// Define LED Matrix Angles //
//////////////////////////////
byte degree0[] =
{
  B00000010,
  B00000010,
  B00000010
};

byte degree45[] =
{
  B00000001,
  B00000010,
  B00000100
};

byte degree_neg45[] =
{
  B00000100,
  B00000010,
  B00000001
};

byte degree90[] =
{
  B00000000,
  B00000111,
  B00000000
};

//////////////////////////////////
// Display Angles on LED Matrix //
//////////////////////////////////
void display_angles(float front_left_angle, float front_right_angle, float back_left_angle, float back_right_angle) {
 
  delay(100);
 byte fullDisplay[] =
{
  B00000000,
  B00000000,
  B00000000,
  B00000000,
  B00000000,
  B00000000,
  B00000000,
  B00000000
};

  ///////////////
  // Top Right //
  ///////////////
  for(int i = 0; i < 3; i++)
  {
    fullDisplay[i] = fullDisplay[i] | wheelAngle(front_right_angle)[i];
  } 
  
  //////////////////
  // Bottom Right //
  //////////////////
  for(int i = 0; i < 3; i++)
  {
    fullDisplay[i+5] = fullDisplay[i+5] | wheelAngle(back_right_angle)[i]; 
  }
  
  //////////////
  // Top Left //
  //////////////
  for(int i = 0; i < 3; i++)
  {
    fullDisplay[i] = fullDisplay[i] | wheelAngle(front_left_angle)[i] << 5;
  }
  
  /////////////////
  // Bottom Left //
  /////////////////
  for (int i = 0; i < 3; i++)
  {
    fullDisplay[i+5] = fullDisplay[i+5] | wheelAngle(back_left_angle)[i] << 5; 
  } 
  
  // Write to display
  for(int i = 0; i < 8; i++){
    lc.setRow(0, i, fullDisplay[i]); 
  }
}

// Return current angle of wheels 
byte* wheelAngle(float angle)
{
  if((angle >= 0 && angle < 30) || (angle < 0 && angle > -30))  
  {
    return degree0; 
  }
  else if(angle >= 30 && angle < 75)
  {
    return degree45; 
  }
  else if(angle <= -30 && angle > -75) 
  {
    return degree_neg45;
  }
  else if(angle > -90 && angle <= -135)
  {
    return degree_neg45;
  }
  else if(angle >= 75 && angle <= 90 || (angle <= -75 && angle >= -90))
  {
    return degree90;
  } 
}

//////////////////////
// Helper Functions //
//////////////////////

// Read accelerometer values
void updateAccVals()
{
  imu.readMag();
  imu.readAccel(); 
  delay(500);
}

float tempRoll = 0.0;
// Return roll values.
float retRoll(float ay, float az)
{
  roll = atan2(ay, az);
  roll *= 180.0/PI;
  
  if(roll < tempRoll - 0.5 || roll > tempRoll + 0.5) 
  {
    tempRoll = roll;
    return roll;
  }
  
  return tempRoll; 
}

float tempPitch = 0.0;
// Return pitch values.
float retPitch(float ax, float ay, float az)
{
  pitch = atan2(-ax, sqrt(ay * ay + az * az));
  pitch *= 180.0/PI;
  
  if(pitch < tempPitch - 0.5 || pitch > tempPitch + 0.5)
  {
    tempPitch = pitch;
    return pitch;
  }
  
  return tempPitch;
}

// Return heading values.
float retHeading(float my, float mx)
{
  if(my == 0)
    heading = (mx < 0) ? 180.0 : 0;
  else
    heading = atan2(mx, my);
    
  heading -= DECLINATION * PI/180;
  
  if(heading > PI) heading -= (2*PI);
  
  else if (heading < -PI) heading += (2 * PI);
  
  else if (heading < 0) heading += 2 * PI;
  
  //Convert from radians to degrees
  heading *= 180.0 / PI;
  
  Serial.print("Heading: " ); 
  Serial.println(heading);
  
  return heading;
} 

// Print array of chars to 7 Seg Display 
void segStringSPI(const int pin, String toSend)
{
  digitalWrite(pin, LOW);
  
  for(int i = 0; i < 4; i++)
  {
     SPI.transfer(toSend[i]); 
  }
  digitalWrite(pin, HIGH);
}

// Clear all displays.
void clearDisplaySPI(int pin)
{
  digitalWrite(pin, LOW);
  SPI.transfer(0x76);
  digitalWrite(pin, HIGH);
  
}
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

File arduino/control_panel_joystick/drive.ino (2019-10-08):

void sendJoyMessage(){
  joy_msg.header.stamp = nh.now();
  joy_msg.axes[0] = joy.getX();
  joy_msg.axes[1] = joy.getY();
  for (int i = 0; i < drive_mode_count; i++){
    joy_msg.buttons[drive_mode_button_ids[i]] = 0;
  }
  joy_msg.buttons[drive_mode_button_ids[driveMode.getActiveButton()]] = 1;
  joyPub.publish( &joy_msg );
}



  
void drive_loop() {
  static unsigned long lastSend = 0;
  bool valuesChanged = false;
  
  // FIXME: QUICK HACK TO REPURPOSE MOUSE BUTTON FOR EVENT FLAGGING
  if ( mouseButton.checkForButtonChange() ) {
    logFlagPub.publish( &log_flag_msg );
  }
  // If the joystick is centered, allow drive mode switching
  if (joy.getX() == 0 && joy.getY() == 0) {
    valuesChanged = driveMode.checkForButtonChange() || valuesChanged;

//    if ( mouseButton.checkForButtonChange() && mouseButton.read()) {
//      driveMode.forceButtonChange(stop_button_index);
//      isMouseMode = true;
//      valuesChanged = true;
//    }
  }

  // If it's been a while or the joystick has changed, send a packet
  if (valuesChanged || (millis() - lastSend) > minSendInterval){
    sendJoyMessage();
    lastSend = millis();
  }
  
  
}

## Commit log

2017-02-07 Added Arduino code (not integrated into catkin_make yet)
2017-02-08 Added OpenSCAD file for rover model
    [GroverWorkingModel.scad]
2017-02-08 Fixed Arduino type
    [GroverWorkingModel.scad]
2017-02-08 Updated to actual latest version
    [GroverWorkingModel.scad]
2017-02-08 Fixed bug where rover would not stop when joystick was released.
    [command_to_angles.py]
2017-04-08 Added initial script and info file for CAN bus integration.
2017-04-10 Added infrastructure for easier button-remapping.
2017-04-10 Corrected file for previous commit.
    [joy_to_command.py]
2017-04-10 Fixed new command callback
    [canard_test.py]
2017-04-13 Added workaround for serial port being non-functional on (and permanently broken by) first run.
    [canard_test.py]
2017-05-03 Partial addition of ROS integration to the CANard script. Still broken, but close.
    [canard_test.py]
2017-05-06 Modified braking behaviour to not disable steering commands.
2017-05-06 Added message definition for wheel status responses and initial launch file for full rover.
2017-12-19 Fixed isBraking bug
    [GroverWorkingModel.scad]
2017-12-19 Fixed permissions
    [GroverWorkingModel.scad]
2018-02-01 Created script and message infrastructure for sensor data, including fake data producer for the mini-Tycho rover.
2018-02-01 Updated mini-Tycho launch file to add sensor data support
2018-02-02 Updated mini-Tycho model to assume much better printing accuracy, and support mounting a Raspberry Pi case over the front end.
    [GroverWorkingModel.scad]
2018-02-02 Improved readability for max temperature code
2018-02-06 Fixed bugs in first draft of fake sensor data. Now it runs.
    [coallate_display_panel.py, dead_reckoning_position.py, fake_wheel_status.py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]
2018-02-08 Added LED matrix functionality, and fixed the 7 segment methods
2018-03-01 Implemented servo driven warnings. Fixed LED matrix bugs.
2018-04-27 Added functionality for accelerometer and bug fixes for 7 segment displays.
2018-05-30 Update GroverWorkingModel.scad
    Further printing accuracy edits. Added front mount for Raspberry Pi case with camera mount (part number currently unknown).
    [GroverWorkingModel.scad]
2018-07-16 Initial version of Arduino joystick code, and renamed old display panel code.
2018-07-17 Fixed fake_joystick; Changed joystick topic name to tycho/joy; cleaned up launch files.
    [control_panel_joystick.ino, fake_joystick.py, joy_to_command.py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]
2018-07-17 Version 1 of power monitor Arduino firmware, author Chris Miconi.
2018-07-18 Added super basic functioning motor controller code examples.
2018-07-18 Motor controller settings - April 20th, 2017
    [motor_controller_profile.xml]
2018-07-18 Motor controller settings - April 25th, 2017
    [motor_controller_profile.xml]
2018-07-18 Motor controller settings - March 6th, 2018
    [motor_controller_profile.xml]
2018-07-18 Motor controller settings - June 1st, 2018
    [motor_controller_profile.xml]
2018-07-18 Motor controller settings - June 14th, 2018
    [motor_controller_profile.xml]
2018-07-18 Motor controller settings - June 28th, 2018. Works with example CAN code.
    [motor_controller_profile.xml]
2018-07-18 FUll-up CAN code for motor controller as of July 3rd, 2018. Mostly functional.
2018-07-18 Added untested heartbeat code to both motor controller and python ends of the CAN bus.
2018-07-18 Fixed ROS startup ordering.
    [command_to_angles.py, dead_reckoning_position.py, fake_wheel_status.py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]
2018-07-18 Added makefile for power monitor Arduino.
2018-07-26 Updated control panel Arduino code for buttons signalling ground, rather than 5V.
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2018-07-27 Updated control interface Arduino code to use ROS messages.
2018-07-27 Added ROS messaging to power monotir Arduino code.
2018-07-27 Added mouse message to control panel Arduino code; fixed joystick direction.
    [classes.h, control_panel_joystick.ino, mouse.ino]
2018-07-27 Added helper script for rebuilding Arduino ROS message libraries.
2018-07-27 It might help if I committed the power monitor message definition itself...
2018-07-28 Full re-write of joy_to_command.py. Cleaned up control flow, cleaned up and added reduntant check for braking button, cleaned up formatting, modified message-building mechanism to allow resending old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
    [joy_to_command.py]
2018-07-28 It runs now, but no modes other than normal do anything, and normal doesn't drive.
    [joy_to_command.py]
2018-07-30 Fixed high-level driving modes.
    [joy_to_command.py]
2018-07-31 Adjusted fake wheel status message rate to match actual motor feedback rate.
2018-07-31 Fixed bugs with mode-switching.
    [command_to_angles.py, joy_to_command.py]
2018-07-31 Added initial test of IMU reader.
2018-07-31 Added fake version of power monitor to hardwareless test suite.
2018-08-01 initial version of a port of the SparkFun IMU library to Python.
2018-08-01 Add power monitor page to web interface
2018-08-01 IMU reader port runs, but produces incorrect(?) results.
2018-08-08 Adjusted controller profile to not autostart code; correctly read steering temmperature sensor.
    [motor_controller_profile.xml]
2018-08-15 Updated with improved rate limiting, changed CAN interface to work with SocketCAN and CANdleLight firmware instead of default CANable firmware.
2018-08-15 Newer motor controller code
2018-08-16 Tested PID-setting, changed to use currently-unused RPDOs, and directly setting user variables apparently doesn't get a larger range of avilable values.
    [canard_test.py]
2018-08-17 Updated PID-setting to work with current controller code, and updated amp reporting.
2018-08-17 Script to abstract PID-updating ROS message
2018-08-17 Added version of the MC code that works on the ground. Needs major improvements to steering.
2018-08-17 Updated motor controller profile that works on the ground. This is for the right-hand drive motors; the left-hand need to have the drive direction reversed. Also note that the CAN node ID must be man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
    [motor_controller_profile.xml]
2018-08-17 Cleaned up motor controller code to work better with wheel initialization, have lower bytecode count, have consistent whitespace, and hopefully have better steering compensation.
2018-08-17 Added desensitization parameter to joystick x-axis in normal driving mode to reduce steering problems.
    [joy_to_command.py]
2018-08-18 Added Ackermann steering setup for front-wheel-only driving; adjusted joystick deadzones.
2019-01-08 Miscellaneous updates to get the thing to work better, ncluding adding higher-speed front-wheel-steering mode.
2019-04-13 Hacked in a basic tank steering mode on Button 5. Is hacky. Might work.
2019-04-13 fixed mode-switching bug from last commit, fixed tank mode wheel direction.
    [command_to_angles.py, joy_to_command.py]
2019-05-15 Set tank mode button back to front-wheel-steering mode.
2019-05-15 Added basic logger, along with adjustment to report unscaled values from motor controllers for debugging.
2019-05-15 Fixed bug where circlestrafe distance didn't adjust without wiggling the stick.
    [joy_to_command.py]
2019-05-15 Added flagging subsystem to logger, repurposed mouse button to create flags. Added joystick logging
2019-05-15 Removed 'drive backwards' capability from strafe mode to remove sudden direction switches.
2019-06-12 Fixed drive direction for strafe mode.
    [joy_to_command.py]
2019-07-03 code cleanup and minor mode interaction bugfixes.
    [joy_to_command.py]
2019-07-03 Added Joy topic logger. This commit is conflicted with the version currently on the rover, as it is missing any way of running the add_flag code.
    [tycho_logger.py]
2019-07-03 Fixed type-casting bug and logic bug that cancelled each other out, except for over-sending messages. Joystick send rate is now 50Hz, not ~200Hz.
    [control_panel_joystick.ino, drive.ino]
2019-10-08 Broke out wheel pivot-arm lengths by wheel to account for front wheels temprarily having longer arms than the rear. Also fixed the distance measurements for the current wheels.
    [command_to_angles.py]
2019-10-11 Fixed various syntax errors.
    [joy_to_command.py]
2019-10-15 Added preliminary slow-to-halt code to accleration code. Also changed spin-in-place to assume rear wheels are locked.
2019-10-16 Added notes about rosparam database and joystick exponential gain function, also tweaked end-disabling to allow passing the value as a string.
    [Parameter_Base.txt]
2019-10-21 Calibrated smooth-decelleration code, increased upper accel limit to make slowing from high speeds less laggy. May need to icrease limit even more above 2 m/s.
2019-10-30 Rewrote joystick deadzone to have proper 0 handling, removed extra deadzone workarounds that delibrately reduced steering sensitivity. Also bumped the max speed up to 3 m/s and activated first stab a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
    [classes.h, control_panel_joystick.ino, joy_to_command.py]
2019-10-30 Added power monitoring topic to logger, and fixed topic name for high-level commands.
    [tycho_logger.py]
2019-10-30 Removed tank mode, added attempt at dynamic toe-in of wheels, actual applied toe-in is currently a fixed +/-1.5 depending on direction and wheel ID.
    [command_to_angles.py]
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2020-01-25 Updated max speeds and fixed a subtle bug that sometimes disabled reverse driving.
    [joy_to_command.py]
2024-04-26 Minor speed tweaks, file is still unused
    [Parameter_Base.txt]
2024-05-23 Adding early planning model/simulation
    [Tycho_Frame_Planning_Model.scad]
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
